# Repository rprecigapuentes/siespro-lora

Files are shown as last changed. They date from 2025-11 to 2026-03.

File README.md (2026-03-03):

# SIESPRO

<p align="center">
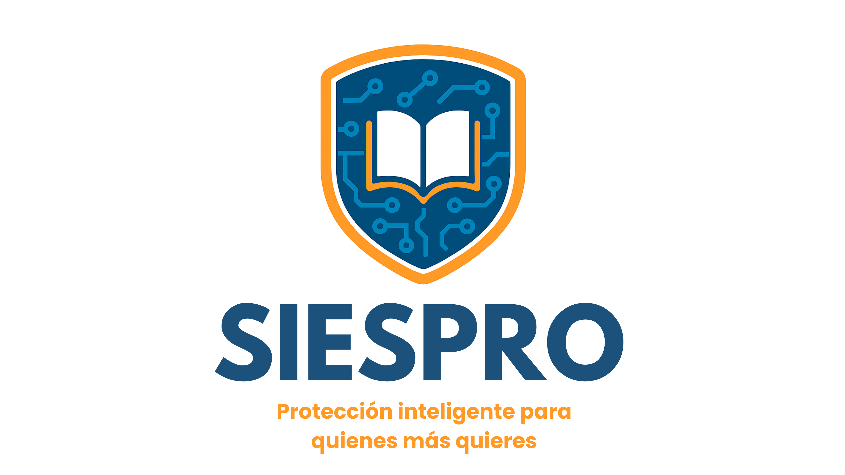
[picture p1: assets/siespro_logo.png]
SIESPRO Logo
  
</p>

<p align="center">
  <em>Sistema Estudiantil de Protección</em>
</p>

<p align="center">
  
  
  
  
  
  
  
  
</p>

---

SIESPRO is an interdisciplinary student project developed at the
[National University of Colombia — Bogotá campus](https://unal.edu.co/)
and presented at **TPI EXPOIDEAS 2025**, the university's annual innovation fair.
The project addresses a tangible problem in Colombian school environments:
**guaranteeing the physical safety of students without compromising their privacy.**

The solution combines IoT hardware, LoRa wireless communication, environmental
sensing, and a Machine Learning model trained from scratch — correlating
ambient variables (temperature, humidity, soil moisture) with RF link-quality
metrics (RSSI, SNR) to classify whether a student node is inside or outside
a defined perimeter. No GPS, no cameras, no biometric data.

Beyond the technical development, SIESPRO was structured as a **simulated
startup**, applying agile methodologies including **Design Thinking**,
**PESTEL analysis**, **Kanban**, **EDT**, **TRL**, and stakeholder-centered
divergence and convergence stages. A survey conducted with parents and school
administrators validated the problem and confirmed demand for a
privacy-preserving approach before any technical work began.

> Visit the project website: [ssiespro.wixsite.com/website-159](https://ssiespro.wixsite.com/website-159)

---

## System Architecture

<p align="center">
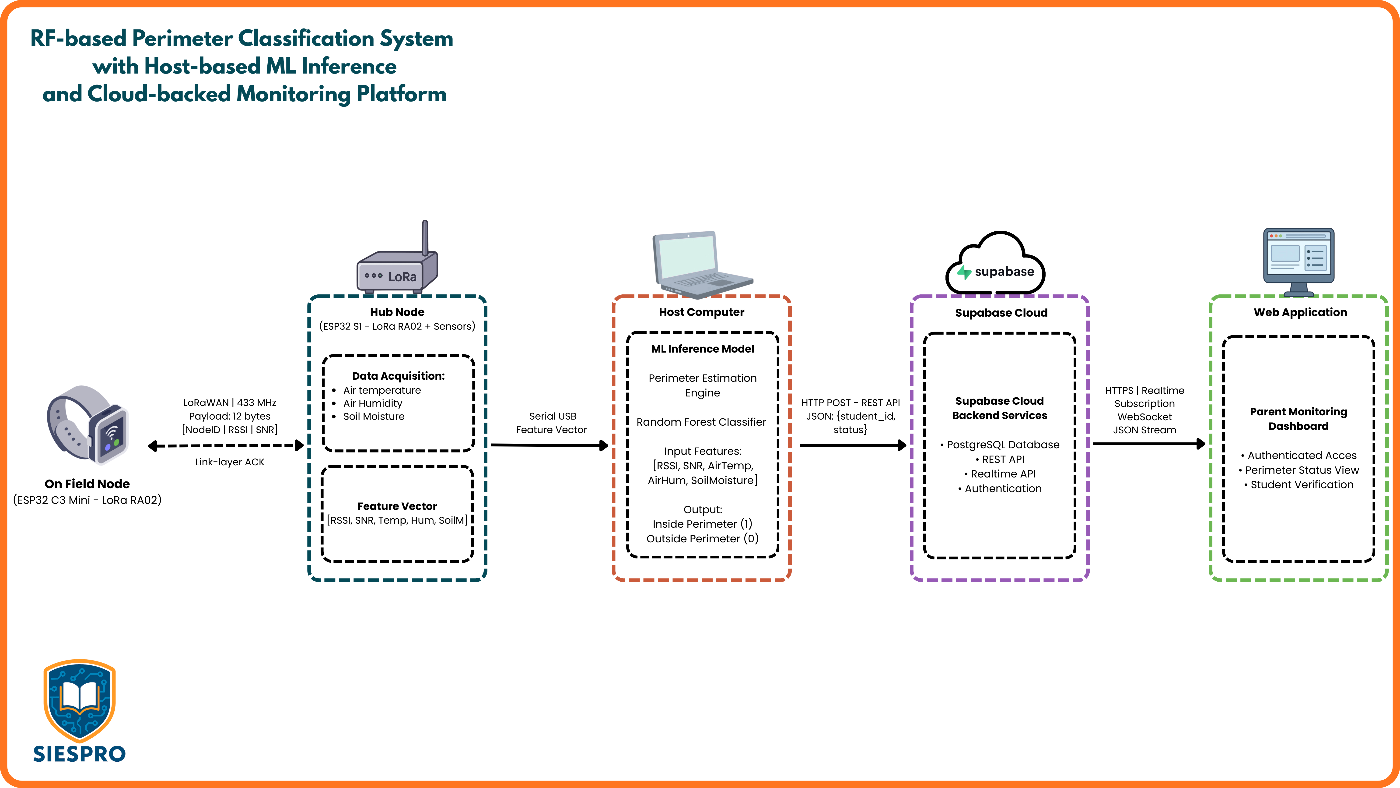
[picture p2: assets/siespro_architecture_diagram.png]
SIESPRO System Architecture
  
</p>

The On Field Node (ESP32-C3 Mini) exchanges LoRa packets with the Hub Node
(ESP32 + sensors). The Hub extracts RSSI and SNR from each ACK frame, bundles
them with local sensor readings, and sends the feature vector to a cloud-hosted
Random Forest classifier via HTTPS. The inference result feeds a real-time
parent-facing dashboard backed by Supabase.

---

## Hardware Prototype

<p align="center">
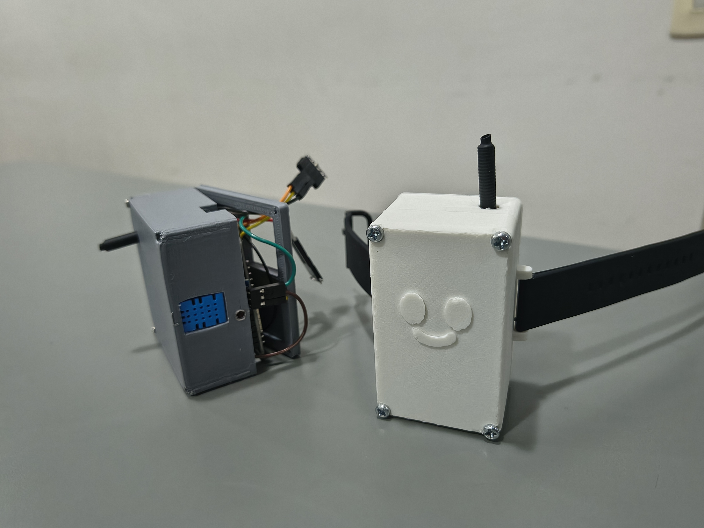
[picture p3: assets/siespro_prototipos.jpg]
SIESPRO Hardware Prototypes
  
</p>

Both nodes were fully assembled and tested on-site during the data collection
phase. Left: Hub Node (ESP32 + SX1278 + DHT11). Right: On Field Node
(ESP32-C3 Mini + SX1278).

---

## Team

SIESPRO was built by a genuinely interdisciplinary team, with each member
assigned a startup role matching their engineering background:

| Role | Name | Discipline |
|---|---|---|
| CEO | Luis Guillermo Vaca Rincón | Electronic Engineering |
| CTO | Rosemberth Steeven Preciga Puentes | Electronic Engineering |
| CFO | Andrés Felipe Castillo Caicedo | Mechanical Engineering |
| COO | Daniela Martínez Sierra | Civil Engineering |
| CCO | Miguel Alejandro Bermúdez Claros | Agricultural Engineering |
| CMO | Camila Stefany Garzón Parra | Anthropology |

---

## Repository Structure

| Folder | Contents |
|---|---|
| `hardware/` | All ESP32 firmware — master node, slave node, sensor tests and basic link tests. Each subfolder contains its own README with pin mappings, operating modes and flash instructions. |
| `frontend_backend/` | Web dashboard (parent monitoring UI) and Supabase backend — REST API, real-time subscriptions and PostgreSQL schema. |
| `3D_models/` | Enclosure and mounting models for the hardware nodes. |
| `assets/` | Project documentation — academic poster (TPI EXPOIDEAS 2025), business plan, PESTEL analysis, infographic, architecture diagram and hardware photographs. |

Each folder contains a dedicated `README.md`. Start with the folder most
relevant to your interest; the sections below suggest entry points by role.

---

## Entry Points by Role

**I want to understand the project**
→ Read [`assets/README.md`](assets/README.md) and review [`assets/siespro_poster.pdf`](assets/siespro_poster.pdf)

**I want to run the hardware**
→ Start at [`hardware/README.md`](hardware/README.md) → follow the recommended reading order inside

**I want to explore the ML model or backend**
→ Go to [`frontend_backend/README.md`](frontend_backend/README.md)

**I want to see the physical device**
→ See [`assets/siespro_prototipos.jpg`](assets/siespro_prototipos.jpg)

---

## Methodologies

| Methodology | Application in SIESPRO |
|---|---|
| Design Thinking | Divergence / convergence stages — problem framing and solution validation with stakeholders |
| PESTEL | Viability analysis across political, economic, social, technological, environmental and legal dimensions |
| Kanban | Sprint task management across the team |
| EDT (WBS) | Work breakdown structure for project planning |
| TRL | Technology readiness level tracking from concept to demo |
| Stakeholder mapping | Parents, school administrators and students as primary stakeholders |

---

## Disclaimer

SIESPRO is an academic research project developed for educational purposes.
System effectiveness depends on site-specific calibration and labeled data
collection. The system is designed to assist institutional safety efforts
and is **not intended for surveillance, behavioral tracking, or any use
outside a consensual, institutional safety context.**

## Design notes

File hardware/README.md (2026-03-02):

# SIESPRO — Hardware Subsystem









Embedded firmware for the SIESPRO perimeter monitoring system.
Implements a point-to-point LoRa network between a master node (ESP32) and a
slave node (ESP32-C3 Mini) using Reliable Transmission with AutoACK.
The link-quality metrics extracted from each ACK — RSSI and SNR — serve as
features for a Random Forest classifier that determines whether the transmitter
is inside or outside a defined perimeter.

> **Sensor data is never transmitted over LoRa.** The radio link is used solely
> as a measurement instrument to extract spatial RF features (RSSI, SNR).
> Environmental data (temperature, humidity, soil moisture) is read locally by
> the master node and sent directly to the backend API via HTTPS.

---

## System Architecture

```mermaid
flowchart LR
    subgraph Master ["Master Node (ESP32)"]
        DHT11["DHT11\ntemp / humidity"]
        HW080["HW-080\nsoil moisture"]
        MCU["ESP32"]
        SX_TX["SX1278\nLoRa TX"]

        DHT11 --> MCU
        HW080 --> MCU
        MCU --> SX_TX
    end

    subgraph Slave ["Slave Node (ESP32-C3 Mini)"]
        SX_RX["SX1278\nLoRa RX + AutoACK"]
    end

    subgraph Backend ["Backend"]
        API["REST API\nhttps://siespro.onrender.com"]
        RF["Random Forest\nclassifier"]
        API --> RF
    end

    SX_TX -->|"TX: SIESPRO\nNetworkID 0x3210\n434 MHz / SF7"| SX_RX
    SX_RX -->|"ACK: RSSI, SNR"| SX_TX
    MCU -->|"HTTPS POST\nJSON: temp, hum, rssi, snr"| API
```

---

## Repository Structure

| Folder | Target Hardware | Purpose |
|---|---|---|
| `basic_tests/` | ESP32 + ESP32-C3 Mini | Point-to-point link validation |
| `master_esp32/` | ESP32 | Main firmware — three operating modes |
| `slave_esp32_mini/` | ESP32-C3 Mini | AutoACK responder — passive |
| `sensors_esp32/` | ESP32 | Isolated sensor verification |
| `library/` | — | SX12XX-LoRa driver (Stuart Robinson) |

---

## Hardware Requirements

| Component | Model | Qty | Role |
|---|---|---|---|
| Microcontroller | ESP32 DevKit v1 | 1 | Master node |
| Microcontroller | ESP32-C3 Mini | 1 | Slave node |
| LoRa transceiver | SX1278 (433 MHz) | 2 | RF link |
| Air sensor | DHT11 | 1 | Temperature + humidity |
| Soil sensor | HW-080 | 1 | Soil moisture (optional) |

---

## Prerequisites

- [PlatformIO IDE](https://platformio.org/install/ide?install=vscode) (VSCode extension)
- Python 3.10+ — required only for `IA_config/dataset_tool/collect_dataset.py`
- `pyserial` — `pip install pyserial`

No additional library installation is needed. The SX12XX-LoRa driver is
vendored locally under `library/` and resolved automatically by PlatformIO
via `lib_extra_dirs` in each `platformio.ini`.

---

## Recommended Reading Order

Follow this order when setting up the system for the first time:

1. `library/` — understand the LoRa driver being used
2. `sensors_esp32/` — verify each sensor independently
3. `basic_tests/` — validate the LoRa link before adding logic
4. `slave_esp32_mini/` — flash the slave node (unchanged across modes)
5. `master_esp32/ACK_config/` — validate AutoACK end-to-end
6. `master_esp32/IA_config/` — collect the training dataset
7. `master_esp32/API_config/` — deploy online inference

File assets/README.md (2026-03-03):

# SIESPRO — Project Documentation



[]()
[]()

SIESPRO (*Sistema Estudiantil de Protección*) is a student
project from the **National University of Colombia — Bogotá campus** that goes
beyond a purely technical implementation. The project was structured around two
complementary axes: a **Design Thinking process** centered on the real needs of
stakeholders, and a **PESTEL analysis** to evaluate the viability and context of
the solution. The technical development (an RF-based perimeter classification
system using LoRa and Machine Learning) is the direct result of that process,
not the starting point.

The core problem addressed is **school child safety without compromising student
privacy**: a perimeter monitoring system that detects whether a student is inside
or outside a defined zone using RF signal features (RSSI, SNR), with no cameras
or biometric data involved.

---

## Project Phases

### Divergence — Problem Discovery

The divergence stage applied Design Thinking tools to identify and validate the
problem before committing to any technical solution. A survey was conducted with
the primary stakeholders — parents and school administrators — confirming both
the existence of the safety concern and the rejection of surveillance-based
approaches (cameras, GPS tracking). The outputs of this stage are:

- [**`siespro_infografia.pdf`**](siespro_infografia.pdf) — Visual summary of the problem space, the
  stakeholder map and the key insight that motivated the solution: families want
  safety guarantees without exposing children to invasive monitoring.

- [**`siespro_slides.pdf`**](siespro_slides.pdf) — Presentation used during the divergence review.
  Contains the PESTEL analysis across the six dimensions (Political, Economic,
  Social, Technological, Environmental, Legal), the survey methodology, results
  and the opportunity framing that bridged the problem into the solution space.

### Convergence — Solution & Validation

The convergence stage produced a defined, implementable solution and evaluated
its real-world viability as a product. The outputs of this stage are:

- [**`siespro_poster.pdf`**](siespro_poster.pdf) — Academic poster presented at **TPI EXPOIDEAS 2025**,
  the semiannual innovation fair of the National University of Colombia. Summarizes
  the full project — problem, methodology, technical architecture, results and
  conclusions — in a single-page format for a general audience.

- [**`siespro_plan_negocios.pdf`**](siespro_plan_negocios.pdf) — Business plan developed to assess the
  commercial and institutional viability of SIESPRO. Covers market analysis,
  value proposition, cost structure, revenue model and go-to-market strategy
  targeting Colombian educational institutions.

---

## Technical Reference

- [**`siespro_architecture_diagram.png`**](siespro_architecture_diagram.png) — System architecture diagram showing
  the data flow across all components: the On Field Node (ESP32-C3 Mini +
  SX1278), the Hub Node (ESP32 + sensors), the host-side ML inference engine
  (Random Forest classifier), the Supabase cloud backend and the parent-facing
  web dashboard. This diagram is the canonical reference for understanding how
  the hardware, firmware, ML model and backend interact
- [**`siespro_logo.png`**](siespro_logo.png) — Official SIESPRO logotype.
  Used as the project's visual identity across documentation, the web platform
  and the academic poster.

---

## Document Index

| File | Phase | Type |
|---|---|---|
| `siespro_infografia.pdf` | Divergence | Infographic |
| `siespro_slides.pdf` | Divergence | Presentation + PESTEL |
| `siespro_poster.pdf` | Convergence | Academic poster — TPI EXPOIDEAS 2025 |
| `siespro_plan_negocios.pdf` | Convergence | Business plan |
| `siespro_architecture_diagram.png` | Technical | System architecture diagram |
| `siespro_logo.png` | — | Brand asset |

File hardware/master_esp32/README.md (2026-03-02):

# Master Node — ESP32








Central node of the SIESPRO system. Reads environmental sensors, maintains a
LoRa link with the slave node to extract RF spatial features (RSSI, SNR from
each ACK), and operates in one of three selectable modes depending on the
project phase.

---

## Operating Modes

| Mode | Folder | Output | Purpose |
|---|---|---|---|
| **ACK** | `ACK_config/` | Serial debug | End-to-end AutoACK link validation |
| **IA** | `IA_config/` | CSV via Serial | Offline dataset acquisition for RF training |
| **API** | `API_config/` | HTTPS POST | Online inference — sends data to backend REST API |

Each mode is a standalone PlatformIO project. Flash only the mode needed for
the current project phase. The slave node firmware does not change across modes.

---

## Structure

```
master_esp32/
├── ACK_config/
│ ├── src/main.cpp
│ └── platformio.ini
├── IA_config/
│ ├── dataset_tool/
│ │ ├── collect_dataset.py
│ │ ├── mediciones_loRa_[2s].csv ← generated at runtime
│ │ └── mediciones_loRa_[3s].csv ← generated at runtime
│ ├── src/main.cpp
│ └── platformio.ini
└── API_config/
├── src/
│ ├── credentials.h ← not committed (see below)
│ └── main.cpp
└── platformio.ini
```

---

## Sensor Configuration

All modes support two sensor configurations selectable at compile time:

| Config | Sensors | CSV columns |
|---|---|---|
| **2S** (default, active) | DHT11 | `temp_C, hum_air_pct, rssi_dBm, snr_dB` |
| **3S** (commented `[3S]`) | DHT11 + HW-080 | `temp_C, hum_air_pct, soil_pct, rssi_dBm, snr_dB` |

To switch to 3S: uncomment all lines marked `[3S]` in both `src/main.cpp`
and (for IA_config) `dataset_tool/collect_dataset.py`. Both files must use
the same config simultaneously.

---

## Pin Mapping

| Signal | GPIO |
|---|---|
| LoRa SCK | 18 |
| LoRa MISO | 19 |
| LoRa MOSI | 23 |
| LoRa NSS | 5 |
| LoRa NRESET | 14 |
| LoRa DIO0 | 2 |
| DHT11 data | 17 |
| HW-080 analog | 33 |

---

## WiFi Credentials (API_config only)

Credentials are **not** stored in `main.cpp`. Create the following file
before building `API_config/`:

**`API_config/src/credentials.h`**
```cpp
#pragma once
#define WIFI_SSID     "your_ssid"
#define WIFI_PASSWORD "your_password"
```

Add it to .gitignore at the repo root:

```
hardware/master_esp32/API_config/src/credentials.h
```

## IA_config — Dataset Tool

IA_config/dataset_tool/collect_dataset.py reads CSV lines from the master
via Serial and writes labeled samples to disk for offline Random Forest training.

```
cd IA_config/dataset_tool
pip install pyserial
python collect_dataset.py
```

### Keyboard controls:

| Key | Action |
| ----- | --- |
| s | Start recording |
| p | Pause recording |
| Space | Toggle label 0 ↔ 1 |
| q | Quit |

Label semantics: 0 = outside perimeter, 1 = inside perimeter.

>The script filters out any Serial line that does not match the expected
>field count (4 for 2S, 5 for 3S). Debug prints in firmware are suppressed
>in IA_config intentionally to avoid parse errors.

## Recommended Phase Sequence

1. ACK_config   →  verify AutoACK link is stable
2. IA_config    →  collect labeled dataset (both classes, multiple positions)
3. API_config   →  deploy trained model to backend, begin online inference

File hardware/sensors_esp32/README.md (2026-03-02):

# Sensor Tests — ESP32






Isolated sensor verification firmware. Use these sketches to confirm correct
wiring and sensor response independently from the LoRa stack before integrating
sensors into the master node firmware.

---

## Structure

```
sensors_esp32/
├── dht11/
│ ├── src/main.cpp
│ └── platformio.ini
└── hw080/
├── src/main.cpp
└── platformio.ini
```

---

## DHT11 — Air Temperature & Humidity

**Pin:** GPIO 17

**Expected Serial output:**

```
Humidity: 54.00% Temp: 21.00 °C / 69.80 °F
```

**Common failure modes:**

| Output | Cause |
|---|---|
| `DHT11 read failed` repeatedly | Wrong GPIO, missing pull-up, or damaged sensor |
| Fixed value that never changes | Sensor not powered (3.3 V required) |
| Values update slower than 1 s | Normal — DHT11 maximum sampling rate is 1 Hz |

> A 10 kΩ pull-up resistor between the data line and VCC is required.
> Most breakout modules include it; bare sensors do not.

---

## HW-080 — Soil Moisture

**Pin:** GPIO 33 (ADC1 — required; ADC2 is unavailable when WiFi is active)

**Expected Serial output:**

```
Soil moisture: 42%
```

**Calibration:**

The `map()` function uses fixed ADC bounds:

```cpp
map(analogRead(SOIL_PIN), 4092, 0, 0, 100)
//                         ^^^^  ^
//                         dry   saturated
```

These values are empirical for a 12-bit ESP32 ADC. If readings at known
dry/wet states do not reach 0% or 100%, adjust the bounds:

1. Read raw ADC with sensor fully dry in air → use that value as the 4092 bound
2. Read raw ADC with sensor fully submerged → use that value as the 0 bound
3. Update both arguments in map() accordingly

>GPIO 33 is input-only on the ESP32 — do not use it for output.
>ADC readings are nonlinear near the rails; values below ~5% and above ~95%
>may be unreliable without additional calibration.

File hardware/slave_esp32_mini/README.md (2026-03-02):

# Slave Node — ESP32-C3 Mini






Passive AutoACK responder for the SIESPRO LoRa network.
The slave node listens for packets matching the project `NetworkID (0x3210)`,
and automatically sends an ACK containing its own RSSI and SNR measurements
back to the master. It carries no sensors and requires no configuration
changes across operating modes.

---

## Role in the System

```
Master (ESP32) ──[TX: "SIESPRO", NetworkID=0x3210]──► Slave (ESP32-C3 Mini)
Master (ESP32) ◄──[ACK: RSSI, SNR]──────────────────── Slave (ESP32-C3 Mini)
```

The RSSI and SNR values embedded in the ACK are the spatial RF features
extracted by the master to feed the Random Forest classifier.

---

## Structure

```
slave_esp32_mini/
├── src/
│ └── main.cpp
└── platformio.ini
```

This firmware is **single and shared** across all master operating modes
(ACK_config, IA_config, API_config). Flash once; no changes needed.

---

## Pin Mapping (ESP32-C3 Mini)

| Signal | GPIO | Note |
|---|---|---|
| SCK | 10 | |
| MISO | 5 | |
| MOSI | 6 | |
| NSS | 7 | |
| NRESET | 3 | |
| DIO0 | 2 | Interrupt input — driven by SX1278, not MCU |

> GPIO2, GPIO8 and GPIO9 are hardware strapping pins on the ESP32-C3.
> The SX1278 drives DIO0 only after boot is complete, so GPIO2 is safe
> as an interrupt input but must not be pulled externally at startup.

---

## LoRa Parameters

Must match the master node exactly:

| Parameter | Value |
|---|---|
| NetworkID | `0x3210` |
| Frequency | 434 MHz |
| Spreading Factor | SF7 |
| Bandwidth | 125 kHz |
| Coding Rate | 4/5 |
| ACK Timeout | 1000 ms |

---

## Flash Instructions

```console
# From slave_esp32_mini/ directory
pio run --target upload
pio device monitor --baud 115200
```

Expected Serial output on each received packet:

```
LocalNetworkID,0x3210,ReceivedPayloadCRC,0x<CRC>,RSSI,-<n>dBm,SNR,<n>dB
```

Packets with a non-matching NetworkID are silently discarded by the library.

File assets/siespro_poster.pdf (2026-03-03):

Rosemberth Preciga
rpreciga@unal.edu.co

Diseñar el dispositivo portátil (manilla) con las especificaciones técnicas requeridas para la comunicación LoRa, garantizando un uso cómodo y adaptable.

Estructurar el protocolo de comunicación LoRa para la conexión fiable entre dispositivos, receptores y la plataforma de alertas.

Construir el prototipo funcional, integrando los componentes de hardware (dispositivos y receptores) y software (plataforma de alertas).

Evaluar el desempeño técnico del prototipo en un entorno de baja conectividad para validar su alcance, precisión y escalabilidad

Costos unitarios estimados: Manilla ≈ $114.210 COP
Host ≈ $141.800 COP.

En Colombia, el mercado proyecta 53.000 instituciones educativas

Modelo Random Forest que determina condición dentro/fuera del perímetro.

# Modelo económico

# Introducción

# Objetivos

# Partes interesadas

# Solución

# Limitaciones y Requerimientos

Grupo 22

Luis Vaca
lvacar@unal.edu,co

Miguel Bermudez
mibermudez@unal.edu.co

Andres Castillo
ancastilloc@unal.edu.co

Camila Garzón
cgarzonpa@unal.edu.co

Daniela Martínez
dmartinezsi@unal.edu.co

PSrotec

I

cióEn inteSligentPe paraRquienOes más quieres

### Prototipo funcional completo con flujo IoT:

hardware, LoRa, backend y visualización web.

Limitaciones:

Entrenamiento propio del
modelo IA.
Tamaño actual del hardware. Robustez de la carcasa.
Detección limitada a
“dentro/fuera” del perímetro.

¿Sabías que, en Colombia, a enero de
2025, se registraron 3.201 solicitudes de
búsqueda de menores?

Aunque existe normativa sobre el cuidado escolar, no hay un protocolo unificado ni herramientas tecnológicas que permitan reaccionar de inmediato ante una salida no autorizada.

La mayoría de los colegios aún dependen de torniquetes, códigos QR o registros manuales, sistemas limitados a los puntos de acceso y que no cubren el perímetro real.

SIESPRO propone una alternativa no invasiva basada en comunicación inalámbrica, capaz de identificar si un estudiante está dentro o fuera del colegio sin rastreo continuo ni infraestructura compleja.

Acudientes: Necesitan información rápida y confiable para garantizar la seguridad de sus hijos y reducir la incertidumbre ante posibles riesgos.

Docentes: Manejan sobrecarga operativa y necesitan apoyo tecnológico que facilite la supervisión y reduzca fallas humanas.

Directivos: Requieren protocolos claros, trazabilidad y herramientas que fortalezcan la gestión institucional y la respuesta ante emergencias.

Estudiantes: Especialmente menores de edad, necesitan un entorno seguro y un sistema no invasivo que permita monitoreo sin afectar su autonomía.

Desarrollar una solución tecnológica accesible que permita detectar salidas no autorizadas mediante comunicación inalámbrica de largo alcance (LoRa), sin rastreo invasivo y adaptable a instituciones con baja conectividad.

Objetivo General:

Determinar la viabilidad económica del sistema mediante el análisis de costos de producción, el modelo de negocio (TAM-SAM-SOM) y la proyección financiera.

Objetivos específicos:

Requerimientos:

Integración HW–FW–LoRa–API. Pruebas de campo para
calibración.
Nodo maestro con energía e internet mínimo.
Cumplimiento de Ley 1581 y consentimiento informado.

SOM

SAM

TAM

Manilla LoRa impresa en 3D, capaz de responder al polling del nodo maestro.

Este representa un 20% del mercado total, es decir 10.600
A co | instituciones.

rto/mediano plazo se aspira que
este represente el 10% del SAM, es
decir 1.060 instituciones educativas

TIR: 73.9% y VPN positivo: $1.374 millones COP a 5 años, indicando alta rentabilidad y recuperación en menos de 1.88 años.

Modelo híbrido HaaS + SaaS: Pago por instalación inicial + suscripción anual por estudiante, lo que facilita adopción y reduce barreras de inversión.

Ventaja competitiva: arquitectura LoRa/LoRaWAN reduce CAPEX, permite operar sin internet y abre acceso al 90% de instituciones con infraestructura limitada.

Nodo maestro obtiene RSSI, SNR y variables ambientales para clasificación.

Dashboard web que muestra estado del estudiante y genera alertas en tiempo real.

API desplegada y conexión con base de datos en la nube para almacenamiento y procesamiento.

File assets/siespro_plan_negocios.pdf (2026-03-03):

## Plan de Negocios: SIESPRO (Sistema Inteligente de Seguridad y Permanencia Escolar)

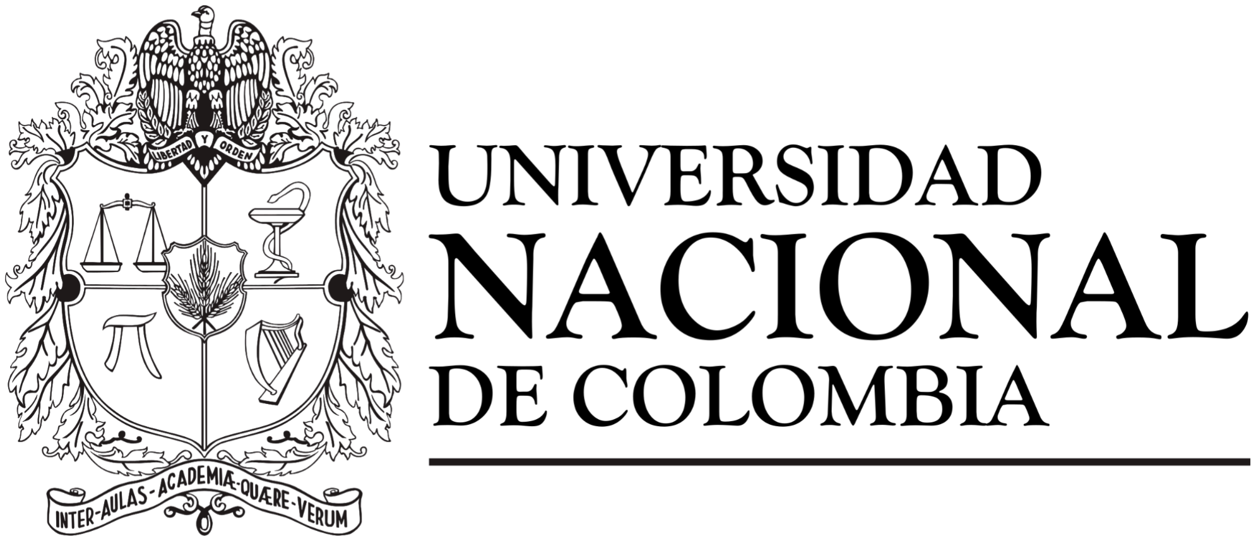
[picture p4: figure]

Autores:
Andrés Felipe Castillo Caicedo Daniela Martínez Sierra
Luis Guillermo Vaca Rincón Miguel Alejandro Bermúdez Claros Rosemberth Steeven Preciga Puentes Camila Stefany Garzón Parra

Taller de Proyecto interdisciplinario Universidad Nacional de Colombia

Fecha: Noviembre 30 2025

Resumen
SIESPRO es un sistema de control de asistencia escolar diseñado y adaptada para la realidad de Latinoamérica y en especial de Colombia. Permite el uso de una solución no invasiva sustentada en la tecnología LoRa y dispositivos wearables y que asegura el control de la salida no autorizada de estudiantes (de 3 a 12 años) en instituciones educativas que tienen una alta probabilidad de baja conectividad.
El modelo de negocio está enfocado hacia una suscripción B2B (Business-to-Business) con las instituciones educativas y posee un alto valor social, ético y operativo: reduce el riesgo de las salidas no autorizadas, disminuye la sobrecarga laboral del docente y proporciona tranquilidad a los padres. El análisis financiero muestra que la viabilidad económica tiene una Tasa Interna de Retorno (TIR) del 73.9% y el Valor Presente Neto (VPN) es de $1.374 millones COP a 5 años, mostrando una fuerte rentabilidad y un tiempo de recuperación de la inversión inferior a los 2 años. SIESPRO se establece en un nuevo nicho de mercado (Océano Morado), una combinación de la innovación tecnológica y el impacto social en la seguridad infantil.

### 1. Fundamentación y origen de la idea de negocio

Para comenzar, es fundamental tener en cuenta los riesgos externos y contextuales que atraviesan la seguridad escolar. Datos proporcionados por la UBPD (Unidad de Búsqueda de Personas Dadas por Desaparecidas), con corte a enero de 2025, registran 3.201 solicitudes de búsqueda de niños, niñas y adolescentes. De estas personas, 88 son niñas, 182 son niños y 2.914 son adolescentes. Esta situación agrava las preocupaciones de los padres y acudientes, caracterizando las salidas no autorizadas como un riesgo real y latente, que va más allá de un simple problema disciplinario, constituyéndose en un riesgo de seguridad.

Aunque la normatividad colombiana establece responsabilidades claras frente al cuidado de menores en jornada escolar (Función Pública, Norma 6405), en la práctica no existe un protocolo específico; por este motivo, el protocolo no está unificado, ni tecnológicamente soportado para atender eventos en los que un niño se aleja del aula, sale del plantel o se pierde dentro de la institución.

Este vacío es más preocupante si se contrasta con datos que dan cuenta de la desigualdad en la infraestructura escolar en Colombia. Esto se ve reflejado en situaciones en las cuales no se cuenta ni siquiera con las barreras físicas nombradas anteriormente, delegando toda la responsabilidad en los docentes encargados de los niños. Por otro lado, Mazo (2025) habla de cómo más de 21.000 sedes educativas carecen de acceso a internet, y un aproximado de 5.000 carecen de electricidad, imposibilitando el uso de soluciones tecnológicas basadas en conectividad Wi-Fi o plataformas digitales. En otras palabras, los colegios no solo carecen de protocolos, sino que tampoco poseen condiciones técnicas que permitan implementar tecnologías convencionales de monitoreo estudiantil.

2. Propuesta de valor y componente de innovación

La propuesta de SIESPRO no es solo tecnológica, sino principalmente ética y contextual. Su valor se centra en transformar la gestión de la seguridad escolar, pasando de un modelo reactivo, basado en barreras físicas y vigilancia humana sobrecargada, a un sistema proactivo, de bajo requerimiento técnico y diseñado para adaptarse a las profundas inequidades infraestructurales del sistema educativo colombiano.

SIESPRO se posiciona como la herramienta esencial para que las instituciones educativas garanticen la permanencia de estudiantes entre 3 y 12 años sin sacrificar su autonomía o privacidad. El equipo SIESPRO ofrece a la comunidad educativa tranquilidad y prevención mediante la detección inmediata de eventos de salida no autorizada del perímetro seguro. Adicionalmente, el sistema actúa como un apoyo continuo, aliviando la carga docente y reduciendo la vulnerabilidad de la vigilancia generada por la sobrecarga de tareas que cumple el personal escolar.

Frente a esta situación, es necesario tener presente que actualmente el mercado de seguridad escolar ofrece principalmente tres tipos de soluciones: sistemas de cámaras de vigilancia, aplicaciones de control de asistencia y tecnologías de rastreo de ubicación precisa como GPS o soluciones RFID. Es en este panorama en el que SIESPRO se impone como una alternativa respetuosa y efectiva frente a las dificultades de las principales competencias. Al no rastrear la ubicación específica del estudiante dentro de la institución, se asegura el cumplimiento de la ley y se promueve la confianza necesaria en acudientes y docentes, lo que constituye una ventaja decisiva.

De esta forma, la innovación de SIESPRO se expresa en su capacidad para ofrecer una solución tecnológica, pero contextualizada para superar las barreras del entorno educativo. El proyecto está diseñado con el propósito de ser escalable y adaptable: mientras que la fase inicial de exploración utiliza conectividad Wi-Fi para facilitar las pruebas piloto, la base tecnológica se encuentra orientada a evolucionar hacia LoRaWAN (una red de largo alcance y bajo consumo). Este diseño permite que el sistema pueda ser operable en entornos rurales o con infraestructura precaria.

3. Modelo y estrategia de negocio
3.1. Modelo Canvas

El modelo de negocio de SIESPRO ha sido estructurado con el método del Business Model

Canvas (BMC) creando un modelo mixto de Hardware as a Service (HaaS) y Software as a Service (SaaS) centrado en el espacio de mercado que ha sido denominado Océano Morado a partir de su base ética, de privacidad y tecnología accesible.

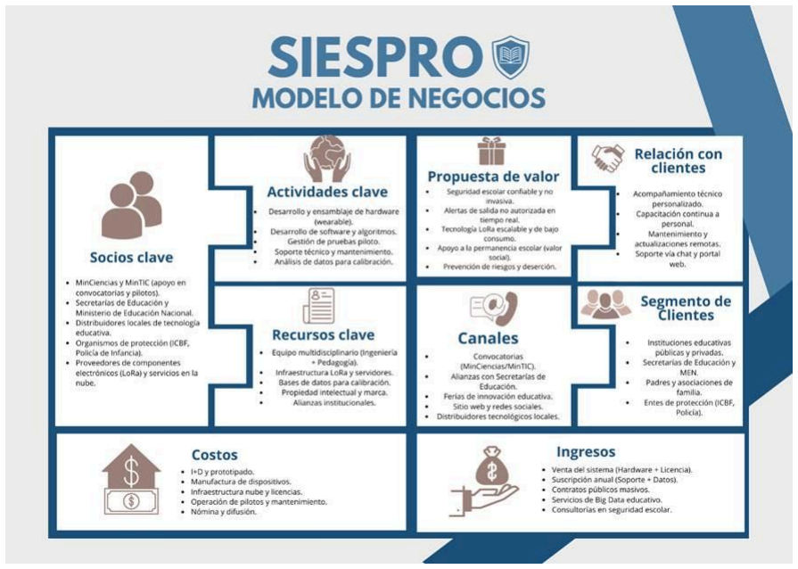
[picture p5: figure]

Figura 1.Business Model Canvas (BMC) de SIESPRO Fuente: Elaboración propia basada en Osterwalder y Pigneur (2010).

3.1.1. Segmentos de clientes (CS)

Este modelo contempla cuatro partes interesadas relevantes a las que se interpela de manera diferente para garantizar la compra del producto: 1) Directivo/Administrativo: quien toma la decisión de aprovisionamiento motivado por la reducción del riesgo legal e incurrido en reputación; 2) Docente/Personal: quien es el usuario directo del sistema y quiere la seguridad de los estudiantes, pero igualmente quiere aliviarse con el desgaste de la sobrecarga de ejecución; 3) Acudiente/Padre de Familia: motivado por la tranquilidad y la notificación rápida; y 4) Niño/Estudiante: quien es el sujeto central del servicio y la seguridad y protección es el objetivo final.

3.1.2. Propuesta de valor (VP)

La propuesta se orienta a la Seguridad Escolar No Invasiva, que pretende advertir las salidas no permitidas y los extravíos en el tiempo real mediante detecciones perimetrales, distinguiéndose por su ética, así como por su alineamiento con la Ley 1581 (Protección de Datos), pues no se intenta rastrear la ubicación del menor, sino que mediante un acuso de respuesta intenta detectar la presencia/ausencia en un perímetros definido, reduciendo así la invasión de la privacidad, además de que el sistema promueve la adaptabilidad en la baja conectividad y grandes distancias dentro del campus gracias a la buena utilización de la tecnología LoRa.

3.1.3. Canales (CH)

La comercialización de SIESPRO se apoya en una estrategia de Venta Directa Institucional (B2B), fortaleciendo la confianza y el acompañamiento técnico a las instituciones. Los canales de penetración incluyen la venta directa a colegios privados y las alianzas estratégicas con el Ministerio de Educación Nacional (MEN) para instituciones públicas. El soporte se gestiona mediante una plataforma web y una aplicación móvil para la administración de alertas y la comunicación con acudientes.

3.1.4. Relación con clientes (CR)

La relación con clientes es cimentada por medio de la confianza, la transparencia y el soporte técnico continuo. Para cumplir con esto se requiere capacitación al personal y el uso protocolo claro frente al consentimiento informado. Este protocolo no es solo una herramienta de gestión, sino un requisito legal crítico que habilita la operación, ya que el proyecto se encuentra sujeto al cumplimiento de la Ley 1581 de 2012 (Protección de Datos Personales). Dicha normativa exige el consentimiento previo, expreso e informado del acudiente, asegurando su derecho a conocer, actualizar, rectificar y suprimir los datos del menor (Ley 1581 de 2012, artículo 7°). La implementación de este protocolo es esencial para abordar la posible resistencia al cambio, garantizando a la comunidad educativa que dicha tecnología se utiliza únicamente con el fin de brindar seguridad y prevención.

3.1.5. Fuentes de ingreso (R$)

Los ingresos se basan en un modelo híbrido recurrente (HaaS + SaaS). Este se compone de dos cobros: 1) un Fee de Instalación Inicial único por el despliegue de la red LoRa (dispositivos Host/Gateways) y la configuración de la plataforma, y 2) una Suscripción Anual/Mensual (Recurrente), que constituye el ingreso principal. Esta suscripción se cobra por estudiante/manilla e incluye el acceso a la plataforma, el mantenimiento continuo del dispositivo wearable y el soporte técnico, amortizando en el tiempo el costo unitario del dispositivo.

3.1.6. Recursos clave (KR)

IA:

Plataforma de IA de Localización: Algoritmos patentados para estimar la posición por

RSSI/SNR.

Patentes de diseño/software.

Red de gateways LoRa.

Hardware:

Módulos LoRa: Componentes electrónicos clave que permiten la comunicación de largo alcance y bajo consumo energético.

Microcontroladores: Uso de ESP32 en nodos esclavos y Arduino en nodos maestros, garantizando un prototipo funcional (TRL 4, 5 y 6).

Diseño de PCB y carcasa: El diseño adaptado de la placa de circuito impreso (PCB) y la carcasa (case) ergonómica del dispositivo wearable (manilla) son recursos físicos de diseño esenciales para la usabilidad y durabilidad.

Plataforma de software y conectividad:

Base de datos en la nube: Donde se almacena la información de asistencia y alertas.

API y Dashboard: Interfaz donde los docentes, directivos y acudientes recibiranr las alertas en tiempo real y gestionaran la información.

Recursos legales

Protocolo de Consentimiento Informado: Asegura el cumplimiento de la Ley 1581 de 2012 (Protección de Datos Personales), exigiendo la autorización previa, expresa e informada del acudiente para el tratamiento de los datos del menor.

Política de tratamiento de datos: Aquí es donde se define el flujo de información; este recurso es indispensable para demostrar la debida diligencia ante la Superintendencia de Industria y Comercio (SIC).

3.1.7. Actividades clave (KA)

Las actividades fundamentales para la realización del proyecto son la innovación tecnológica y la gestión estratégica de la confianza. Con respecto a la innovación, es muy importante el I+D+i porque es el motor de la mejora del algoritmo de detección de distancia basado en RSSI/SNR y su futura evolución a LoRaWAN, asegurando la escalabilidad y la fiabilidad del sistema no invasivo. A su vez, esta actividad intelectual culmina con la actividad operacional por la cual se producen, ensamblan y logísticas de los dispositivos wearables (manillas) y los gateways, asegurando la entrega de hardware diferenciado a través de un procedimiento eficaz económicamente.

El segundo pilar del modelo de negocio es la Gestión de la Confianza, actividad clave para la viabilidad social y legal del proyecto. Esta actividad implica la gestión práctica y estricta de la ética de los datos y la privacidad del menor en cuyo impacto y control se encuentra garantizada la entrega de las pruebas del cumplimiento de la Ley 1581 de 2012 e implementación del Protocolo de Consentimiento Informado.

3.1.8. Estructura de costos (C$)

La estructura de costos presenta una alta proporción de costos variables derivados de la producción de hardware, compensada por una rentabilidad proyectada elevada gracias al modelo de suscripción. La inversión inicial en activos fijos es de $35.000.000 COP, mientras que la necesidad de financiación para cubrir el capital de trabajo asciende a $827.706.313 COP. Los costos unitarios del hardware se estiman en $114.210 COP para la manilla (dispositivo esclavo) y $141.800 COP para el host (dispositivo maestro). Los costos fijos se concentran principalmente en nómina, I+D y gastos administrativos y operativos.

3. 2. Estrategia y Metas de Crecimiento

La estrategia se centra en la adopción temprana en el mercado urbano-conectado, seguida por la migración a tecnología LoRaWAN para penetrar el mercado rural y de baja conectividad, según la matriz ERAC (Estudio de Mercado, 14.3): Crear un nuevo mercado de seguridad escolar no invasiva.

Plazo | Metas Estructuradas y Medibles | Indicadores (KPI)
Corto Plazo (Año 1-2) | Validación y Consolidación: Implementar el piloto en 5 instituciones. Asegurar la certificación TRL 7 (Prototipo demostrado en entorno real) y TRL 8 . Alcanzar el Punto de Equilibrio (Punto de Equilibrio: 1,88 años). | TRL, N.º de colegios implementados, Punto de Equilibrio, Tasa de Churn.
Mediano Plazo (Año 3-4) | Escalabilidad y Expansión: Implementar la migración tecnológica a LoRaWAN. Duplicar la base de clientes. Explorar alianzas público-privadas para subsidios o pilotos en zonas rurales | Retorno sobre la Inversión (ROI), N.º de estudiantes cubiertos, Penetración en mercado rural.

Largo Plazo
(Año 5+)

Liderazgo y Diversificación: Liderar el segmento EdTech de seguridad escolar en Colombia. Exportar el modelo de solución a otros países de LATAM con infraestructuras similares. Diversificar la oferta con trazabilidad de bienestar estudiantil.

TIR, Expansión geográfica, Market Share, LTV
(Lifetime Value).

Tabla 1. SIESPRO. (2025). Metas estructuradas, indicadores y plazos del proyecto [Tabla no publicada].

4. Análisis del Mercado y Ventajas Competitivas
4.1. Análisis del Mercado Objetivo (TAM, SAM, SOM)

El TAM incluye todas las instituciones educativas de preescolar y primaria —nuestra población considerada la de los niños entre 3 y 12 años— dentro del contexto colombiano y de potenciales mercados latinoamericanos. Este universo responde a dos presiones estructurales: la necesidad de mejorar la seguridad infantil y la necesidad de reducir la carga de la supervisión por parte de los docentes y los directivos. En Colombia se registraron más de 53.400 sedes educativas (DANE, 2017), siendo alrededor de 19.600 de educativas oficiales y no oficiales. Esto representa un mercado potencial muy grande de estudiantes susceptibles a obtener mecanismos de control de permanencia seguros y respetuosos con la privacidad de estos. La oportunidad estratégica se puede ampliar aún más a partir de las limitaciones en la infraestructura del país a nivel de conectividad evidenciando un rezago estructural. Ante ello, la arquitectura tecnológica LoRaWAN de SIESPRO —la cual permite no tener dependencia de internet y operar con mínima infraestructura— genera un habilitador clave que busca maximizar el TAM a largo plazo y eliminar gradualmente la brecha digital.

El SAM ( Serviceable Availble Market) se ve definido por la capacidad tecnológica y operativa actual de SIESPRO y su nicho dentro del Océano Morado. En este punto la empresa incluye escuelas que ya tienen capacidad económica o presupuestaria para invertir en seguridad y que buscan activamente alternativas no invasivas. En una segmentación inicial, se proyecta un SAM de 2,160 (Secretaría de Educación del Distrito, 2025) instituciones de la ciudad de Bogotá y sus alrededores en la primera fase (5 años). componiendose de:

- IE Privadas Urbanas: Con alta preocupación por la reputación y la demanda de seguridad por parte de los padres (Buyer Persona Acudiente/Directivo).

- IE Públicas/Semi-urbanas: Con acceso a programas de digitalización (MinCiencias, iNNpulsa) que subsidian la inversión en seguridad preventiva, que se verían beneficiadas por el bajo requerimiento de infraestructura de LoRa.

El SOM (Serviceable Obtainable Market) propone una meta realista de penetración basada en la capacidad de ventas y recursos humanos proyectados para el corto y mediano plazo (1-5 años).

- Año 1: Consolidación del piloto en 5 instituciones, enfocándose en la obtención de la certificación TRL 7 (prototipo demostrado en entorno real) y la validación ética.
- Año 3: Crecimiento acelerado a 25-30 instituciones tras la recuperación de la inversión (Punto de Equilibrio: 1.88 años) y el uso del VPN ($1.374B COP) y la TIR (73.9%) para apalancar la expansión.
- Año 5: Penetración de más de 100 colegios con la consolidación de la migración a la tecnología LoRaWAN, lo que permitirá a SIESPRO atacar segmentos del SAM en áreas de menor conectividad, maximizando su alcance.
4.2. Análisis Competitivo y Ventajas Sostenibles

Tecnología Anti-Brecha Digital: A partir del paso hacia LoRaWAN ya no es necesario realizar inversiones en las infraestructuras que están basadas en redes Wi-Fi para realizar el seguimiento de las personas, por lo que se hace probablemente accesible al 90% de las instituciones de Colombia, basándose en presupuestos que tengan una infraestructura de internet, energía eléctrica u otro tipo de conexión.

Liderazgo Ético y de Privacidad: Al solo llevar el registro de las salidas perimetrales y no de los movimientos dentro del plantel, SIESPRO disminuye el riesgo social de ser percibido como una 'herramienta de sanción' y cumple con la Ley 1581 de 2012 (protección de datos personales).

Modelo de Costo (OPEX): El modelo de suscripción facilita la adopción institucional en el sentido en que la inversión se convierte en gasto operativo predecible y fácil, no existiendo la barrera que suponen los costes del CAPEX de las soluciones basadas en hardware típico.

5. Proyección y Viabilidad Financiera (2025-2029)

El análisis se basa en una proyección a cinco años (2025-2029), utilizando los datos del Simulador Financiero 2025. equipo 22 - 5 colegios, el cual fue anexo a los documentos de respaldo.

5.1. Proyección de Ventas

La proyección se basa en la venta de dos productos clave: la Manilla (Dispositivo Esclavo) y el Host (Dispositivo Maestro). Se proyecta un crecimiento anual constante del 5% en cantidades vendidas, con un incremento de precio que asegura la rentabilidad.

Indicador (COP) | 2025 (Año 1) | 2026 (Año 2) | 2027 (Año 3) | 2028 (Año 4) | 2029 (Año 5)
Ingresos Totales | $2.194.000.000 | $2.390.410.200 | $2.622.009.824 | $2.840.314.309 | $3.094.728.998
Costo de Ventas (CV) | $386.217.000 | $417.213.499 | $450.721.808 | $486.946.206 | $526.107.609
Utilidad Bruta | $1.807.783.000 | $1.973.196.701 | $2.171.288.016 | $2.353.368.102 | $2.568.621.388

Tabla 2. SIESPRO. (2025). Proyección de ventas [Tabla en anexos].

5.2. Inversión Inicial y Estructura de Costos (CAPEX y OPEX)
5.2.1. Inversión de Capital (CAPEX)

La inversión inicial total (CAPEX) para la puesta en marcha del negocio se establece en $35.000.000 COP, enfocada en activos a largo plazo y la fase de desarrollo tecnológico.

Rubro CAPEX | Valor (COP) | Concepto
Propiedad, Planta y Equipo | $12.000.000 | Equipos de fabricación y laboratorio.
Muebles y Enseres | $6.000.000 | Mobiliario de oficina.
Equipo de Oficina | $2.000.000 | Computadoras y periféricos.
Patentes / Inv. Intangibles | $5.000.000 | Propiedad intelectual (Modelo IA de RSSI).
Gastos de Puesta en Marcha | $10.000.000 | Registro legal, licencias operativas iniciales.

Inversión total Inicial | **$35.000.000**

Tabla 3. SIESPRO. (2025). Inversión de capital [Tabla en anexos, hoja 2].

5.2.2. Costos Operacionales (OPEX)

Los costos operativos (OPEX) del primer año ascienden a $1.326.861.370 COP, siendo la nómina administrativa y de ventas el componente más significativo, seguido de los costos de producción (CV) y gastos fijos.

Rubro OPEX (Año 1) | Valor (COP)
Nóminas (Admin. y Ventas) | $700.000.000
Costos Operativos/Producción (CV) | $386.217.000
Gastos Fijos (Arriendo, Servicios, etc.) | $55.842.469
Marketing Mix / Otros | $184.801.901
Total OPEX Proyectado | **$1.326.861.370**

Tabla 4. SIESPRO. (2025). Costos operacionales [Tabla en anexos, hojas 2 y 4].

6.3. Viabilidad y Rentabilidad Proyectada

La evaluación de la viabilidad se realiza utilizando los indicadores clave TIR, VPN, ROI y el Punto de Equilibrio, asumiendo una Tasa de Evaluación del Proyecto (WACC) del 21%.

6.3.1. Indicadores de Rentabilidad

Los indicadores demuestran que SIESPRO es un proyecto de alta rentabilidad y bajo riesgo de recuperación, superando ampliamente la Tasa de Evaluación del 21%.

- Tasa Interna de Retorno (TIR): 73.9%
- Análisis: Al ser la TIR ($73.9\%$) significativamente mayor que la Tasa de Evaluación del Proyecto ($21\%$), el proyecto es altamente rentable y atractivo para los inversionistas.

- Valor Presente Neto (VPN): $1.374.494.987 COP
- Análisis: Un VPN positivo y elevado indica que el valor presente de los flujos de caja futuros es superior a la inversión inicial, generando riqueza neta.
- Período de Recuperación de la Inversión: 1.88 años
- Análisis: La inversión inicial se recupera en menos de dos años, lo que se considera un período corto para un proyecto de desarrollo tecnológico (Hardware/Software), mitigando el riesgo de liquidez.
6.3.2. Flujo de Caja del Proyecto
Indicador (COP) | Inversión (Año 0) | 2025 (Año 1) | 2026 (Año 2) | 2027 (Año 3) | 2028 (Año 4) | 2029 (Año 5)
Flujo de Caja del Proyecto | -$827.706.313 | $328.536.385 | $895.732.860 | $1.028.001.030 | $804.318.933 | $942.528.479

Tabla 5. SIESPRO. (2025). Flujo de caja del proyecto [Tabla en anexos, hoja 5].

6.3.3. Punto de Equilibrio y Cobertura

El análisis del Punto de Equilibrio (PE) valida la solidez operativa del negocio, determinando el volumen de ventas necesario para cubrir todos los costos fijos y variables.

- Punto de Equilibrio Total (Unidades): 2.932 Manillas y 7.4 Hosts
- Para alcanzar el punto de equilibrio, SIESPRO debe vender el equivalente a 2.932 Manillas y 7.4 Hosts.
- Margen de Contribución Ponderado: $543.393 COP

Este margen indica que, después de cubrir los costos variables, cada unidad ponderada contribuye positivamente a cubrir los costos fijos y generar ganancias.

6.3.4. Evaluación de Riesgos y Mitigación

El proyecto enfrenta riesgos gestionables, siendo la resistencia al cambio y la ausencia de normativa clara los de mayor impacto.

Categoría de
Riesgo

Riesgo de Mayor Impacto Mitigación y Control

Tecnológico | Falla en la comunicación LoRa (Media-Alta) | Foco en la certificación TRL 7 (Piloto en entorno real). Diseño de gateways energéticamente eficientes para entornos rurales.
Económico | Falta de recursos para implementación (Alta-Alta) | Búsqueda activa de alianzas con entidades gubernamentales (MinCiencias, iNNpulsa) y uso de modelo OPEX (suscripción).
Social | Resistencia al cambio de la comunidad educativa (Alta-Alta) | Campañas de sensibilización y capacitación. Énfasis en el enfoque no invasivo y ético de la solución.
Legal | Ausencia de normativa clara sobre tecnologías de rastreo (Alta-Alta) | Protocolo de consentimiento informado y cumplimiento estricto de la Ley 1581 (Protección de Datos) y Ley 1098 (Protección Integral de la Infancia).

Tabla 6. SIESPRO. (2025). Matriz de riesgos e incertidumbres [Tabla en anexos].

Referencias

Carranza, L. (2017). Infancias, cuerpos y subjetividades en la escuela. Revista Infancias Imágenes, 16(2). Universidad Distrital Francisco José de Caldas. https://revistas.udistrital.edu.co/index.php/infancias/article/view/11627

Pontificia Universidad Javeriana. (2025). Informe LEE 2025: TIC en educación. https://www.javeriana.edu.co/recursosdb/d/lee/inf-113-tic-en-educacion-lee-2025

UNESCO. (2023). Tecnología en la educación: una herramienta para el aprendizaje. https://www.unesco.org/es/articles/informe-de-seguimiento-de-la-educacion-en-el-mundo-2023-tecnol ogia-en-la-educacion-una-herramienta (https://www.unesco.org/es/articles/informe-de-seguimiento-de-la-educacion-en-el-mundo-2023-tecnologia-en-la-educacion-una-herramienta)

Arias, J., & López, F. (2024). Low-Power Long-Range Networks (LoRaWAN) for Monitoring and Safety in Educational Contexts. arXiv:2408.03157. https://arxiv.org/abs/2408.03157 (https://arxiv.org/abs/2408.03157?utm_source=chatgpt.com)

Departamento Administrativo de la Función Pública. (2006). Decreto 6405 de 2006. https://www.funcionpublica.gov.co/eva/gestornormativo/norma.php?i=6405

Mazo, L. (2025, abril 17). Más de 21.000 colegios sin internet y casi 5.000 sin electricidad: radiografía del atraso educativo en Colombia. Infobae.

https://www.infobae.com/colombia/2025/04/17/mas-de-21000-colegios-sin-internet-y-casi-5000-sin-electricidad-radiografia-del-atraso-educativo-en-colombia/ (https://www.infobae.com/colombia/2025/04/17/mas-de-21000-colegios-sin-internet-y-casi-5000-sin-electricidad-radiografia-del-atraso-educativo-en-colombia/)

Unidad de Búsqueda de Personas Dadas por Desaparecidas (UBPD). (2025). Día Internacional de las Manos Rojas 2025 – Balance sobre desapariciones de niños, niñas y adolescentes.
https://unidadbusqueda.gov.co/actualidad/dia-internacional-manos-rojas-2025/

Comité Internacional de la Cruz Roja (CICR). (2024). En Colombia, cada 36 horas desaparece al menos una persona en contexto de conflicto armado y violencia. https://www.icrc.org/es/comunicado-de-prensa/en-colombia-cada-36-horas-desaparece-al-menos-una-persona-en-contexto-conflicto-armado-violencia (https://www.icrc.org/es/comunicado-de-prensa/en-colombia-cada-36-horas-desaparece-al-menos-una-persona-en-contexto-conflicto-armado-violencia)

Teldat. (2024). Internet de las Cosas de Largo Alcance (LoRa): características clave. https://www.teldat.com/es/blog/internet-de-las-cosas-de-largo-alcance-lora/

DANE. (s. f.). ¿Sabías que...?. https://www.dane.gov.co/files/dane-para-ninos/sabias-

Departamento Administrativo de la Función Pública. (s. f.). Norma 49981. https://www.funcionpublica.gov.co/eva/gestornormativo/norma.php?i=49981

Secretaría Distrital de Planeación. (s. f.). ¿Cómo se hace?. https://www.sdp.gov.co/micrositios/ninos-ninas-y-adolescentes/como-se-hace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 (https://www.sdp.gov.co/micrositios/ninos-ninas-y-adolescentes/como-se-hace)

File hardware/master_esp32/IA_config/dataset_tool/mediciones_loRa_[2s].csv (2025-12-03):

timestamp_iso | temp_C | hum_aire_pct | rssi_dBm | snr_dB | label
2025-12-02T18:56:15.045636 | 18.8 | 59.8 | -106.0 | 4.0 | 0
2025-12-02T18:56:20.755798 | 18.8 | 59.5 | -111.0 | -2.0 | 0
2025-12-02T18:56:26.466072 | 18.8 | 59.3 | -120.0 | -7.0 | 0
2025-12-02T18:56:32.175927 | 18.8 | 59.2 | -113.0 | -1.0 | 0
2025-12-02T18:56:39.436645 | 18.8 | 59.0 | -117.0 | -4.0 | 0
2025-12-02T18:56:45.145964 | 18.8 | 58.8 | -115.0 | 0.0 | 0
2025-12-02T18:56:50.854810 | 18.8 | 58.7 | -115.0 | -1.0 | 0
2025-12-02T18:56:56.564372 | 18.8 | 58.6 | -117.0 | -1.0 | 0
2025-12-02T18:57:02.273006 | 18.8 | 58.4 | -113.0 | 0.0 | 0
2025-12-02T18:57:07.982450 | 18.8 | 58.4 | -115.0 | 0.0 | 0
2025-12-02T18:57:13.691577 | 18.8 | 58.3 | -113.0 | 2.0 | 0
2025-12-02T18:57:19.400438 | 18.8 | 58.2 | -114.0 | 0.0 | 0
2025-12-02T18:57:25.109836 | 18.8 | 58.1 | -111.0 | 4.0 | 0
2025-12-02T18:57:30.819067 | 18.8 | 58.1 | -118.0 | -2.0 | 0
2025-12-02T18:57:36.527656 | 18.8 | 58.0 | -117.0 | -2.0 | 0
2025-12-02T18:57:42.237275 | 18.8 | 58.0 | -125.0 | -8.0 | 0
2025-12-02T18:57:47.946317 | 18.8 | 58.0 | -125.0 | -7.0 | 0
2025-12-02T18:57:55.206541 | 18.8 | 57.9 | -120.0 | -5.0 | 0
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

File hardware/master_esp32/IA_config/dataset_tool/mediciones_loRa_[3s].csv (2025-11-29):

timestamp_iso | temp_C | hum_aire_pct | hum_tierra_pct | rssi_dBm | snr_dB | label
2025-11-29T14:23:47.141273 | 20.7 | 57.4 | 5.0 | -48.0 | 9.0 | 0
2025-11-29T14:23:47.141960 | 20.7 | 57.4 | 6.0 | -53.0 | 9.0 | 0
2025-11-29T14:23:47.142611 | 20.7 | 57.4 | 6.0 | -54.0 | 10.0 | 0
2025-11-29T14:23:47.143293 | 20.7 | 57.5 | 5.0 | -46.0 | 9.0 | 0
2025-11-29T14:23:47.143893 | 20.7 | 57.5 | 6.0 | -60.0 | 10.0 | 0
2025-11-29T14:23:47.144427 | 20.7 | 57.5 | 5.0 | -66.0 | 9.0 | 0
2025-11-29T14:23:47.144943 | 20.7 | 57.5 | 6.0 | -50.0 | 9.0 | 0
2025-11-29T14:23:47.145452 | 20.7 | 57.6 | 5.0 | -53.0 | 9.0 | 0
2025-11-29T14:23:47.146003 | 20.7 | 57.6 | 6.0 | -50.0 | 10.0 | 0
2025-11-29T14:23:47.146525 | 20.6 | 57.6 | 6.0 | -52.0 | 10.0 | 0
2025-11-29T14:23:47.147051 | 20.6 | 57.7 | 5.0 | -53.0 | 9.0 | 0
2025-11-29T14:23:47.147619 | 20.6 | 57.7 | 5.0 | -52.0 | 10.0 | 0
2025-11-29T14:23:47.148150 | 20.6 | 57.7 | 6.0 | -53.0 | 9.0 | 0
2025-11-29T14:23:47.148695 | 20.6 | 57.7 | 6.0 | -52.0 | 10.0 | 0
2025-11-29T14:23:47.149212 | 20.6 | 57.7 | 5.0 | -52.0 | 9.0 | 0
2025-11-29T14:23:47.149735 | 20.6 | 57.7 | 7.0 | -53.0 | 10.0 | 0
2025-11-29T14:23:47.765773 | 20.6 | 57.7 | 6.0 | -54.0 | 9.0 | 0
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

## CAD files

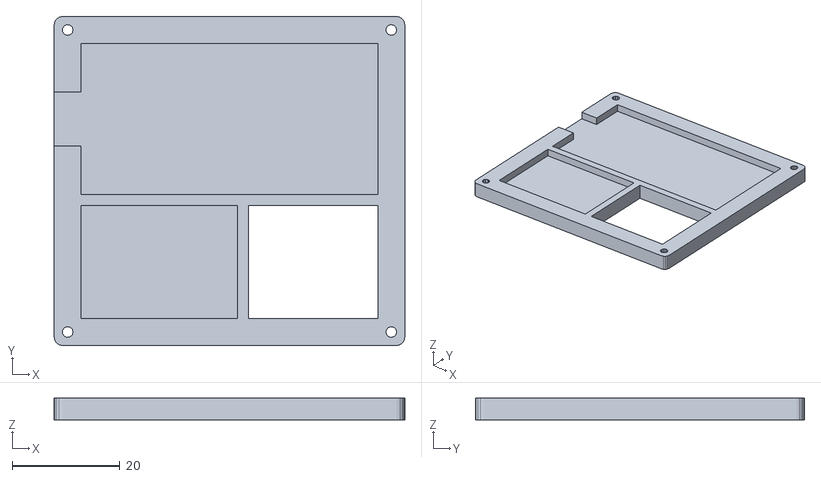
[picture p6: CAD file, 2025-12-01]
3D_models/master/Piso.stl
65.0 x 61.0 x 4.00

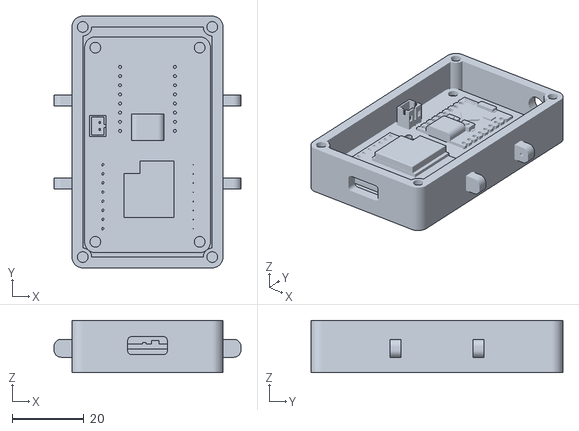
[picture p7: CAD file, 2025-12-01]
3D_models/slave/Waistband_Alltogether_STL.stl
52.0 x 70.0 x 14.5

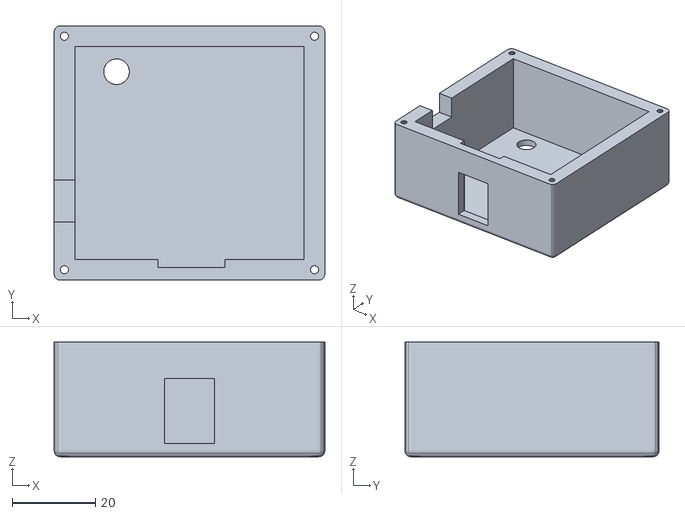
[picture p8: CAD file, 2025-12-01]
3D_models/master/PT.stl
65.0 x 61.0 x 27.5

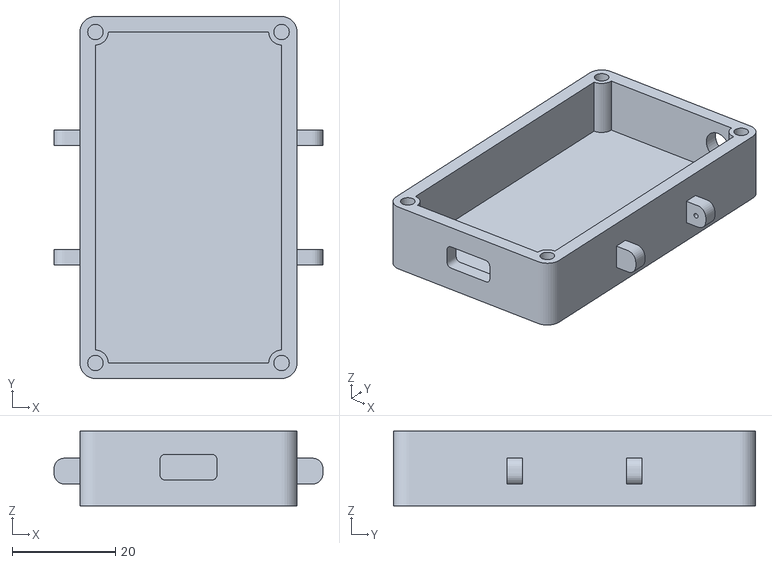
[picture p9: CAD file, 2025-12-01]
3D_models/slave/Base_waistband_stl.stl
52.0 x 70.0 x 14.5

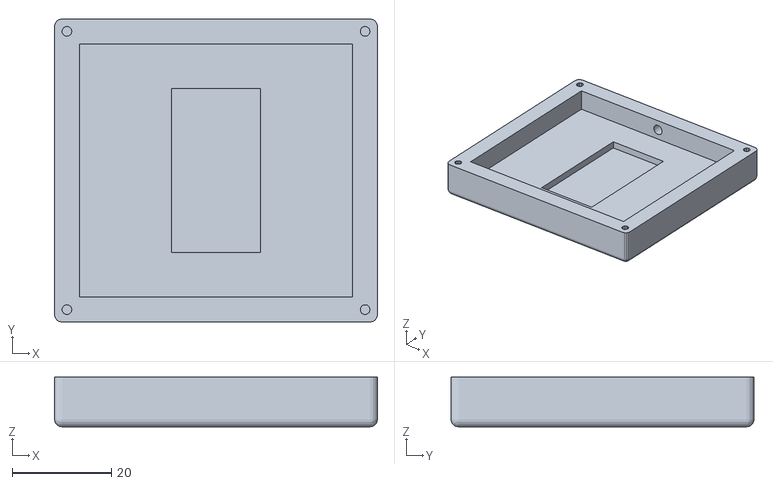
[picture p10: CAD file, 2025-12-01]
3D_models/master/PB.stl
65.0 x 61.0 x 10.0

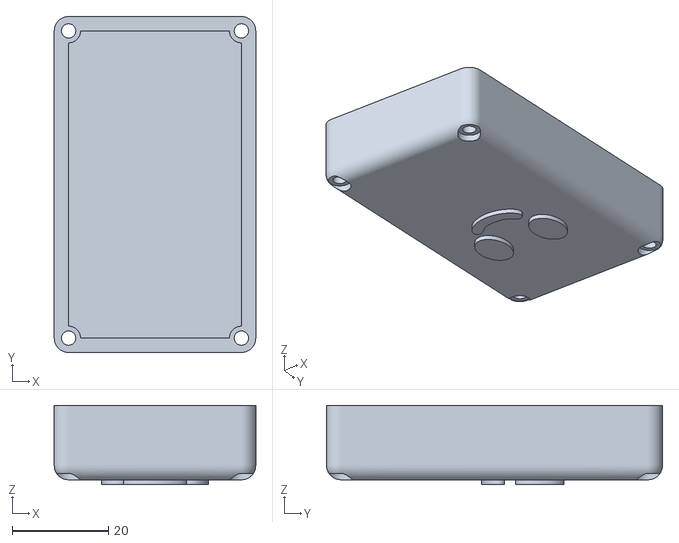
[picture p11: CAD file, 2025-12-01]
3D_models/slave/Top_WaistbandSTL.stl
42.0 x 70.0 x 16.5

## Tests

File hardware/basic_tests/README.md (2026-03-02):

# Basic Tests — LoRa Point-to-Point Link Validation






Minimum firmware to verify SPI wiring and LoRa radio connectivity between the
ESP32 (transmitter) and the ESP32-C3 Mini (receiver) before deploying any
application logic. Run this test first whenever hardware changes are made.

> **This test does not use AutoACK or NetworkID filtering.**
> It is raw unidirectional transmission. For end-to-end AutoACK validation,
> proceed to `master_esp32/ACK_config/`.

---

## Structure

```
basic_tests/
├── esp32/ ← Transmitter (ESP32 DevKit)
│ ├── src/main.cpp
│ └── platformio.ini
└── esp32_mini/ ← Receiver (ESP32-C3 Mini)
├── src/main.cpp
└── platformio.ini
```

---

## Pin Mapping

### ESP32 — Transmitter

| Signal | GPIO |
|---|---|
| SCK | 18 |
| MISO | 19 |
| MOSI | 23 |
| NSS | 5 |
| NRESET | 14 |
| DIO0 | 2 |

### ESP32-C3 Mini — Receiver

| Signal | GPIO |
|---|---|
| SCK | 10 |
| MISO | 5 |
| MOSI | 6 |
| NSS | 7 |
| NRESET | 3 |
| DIO0 | 2 |

> GPIO2, GPIO8 and GPIO9 are strapping pins on the ESP32-C3 — avoid using
> them for LoRa signals. GPIO2 is assigned to DIO0 (interrupt input only,
> driven by the SX1278, not by the MCU at boot).

---

## LoRa Parameters

Both nodes must use identical RF settings:

| Parameter | Value |
|---|---|
| Frequency | 434 MHz |
| Spreading Factor | SF7 |
| Bandwidth | 125 kHz |
| Coding Rate | 4/5 |
| TX Power | 10 dBm |

---

## How to Run

1. Open `esp32/` as a PlatformIO project and flash the transmitter.
2. Open `esp32_mini/` as a separate PlatformIO project and flash the receiver.
3. Open two Serial Monitor sessions simultaneously (115200 baud each).

**Transmitter output (expected):**

```
10dBm Packet> Hello World 1234567890* BytesSent,23 PacketsSent,6
```

**Receiver output (expected):**

```
8s Hello World 1234567890*,RSSI,-44dBm,SNR,9dB,Length,23,Packets,7,Errors,0,IRQreg,50
```

**Receiver timeout (no packets for 60 s):**

```
112s RXTimeout
```

---

## Pass Criteria

| Metric | Expected range |
|---|---|
| RSSI | > −100 dBm at short range |
| SNR | > 0 dB |
| Errors | 0 at < 10 m distance |

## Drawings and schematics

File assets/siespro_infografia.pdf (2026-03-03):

# SIESPRO

## Sistema estudiantil de protección

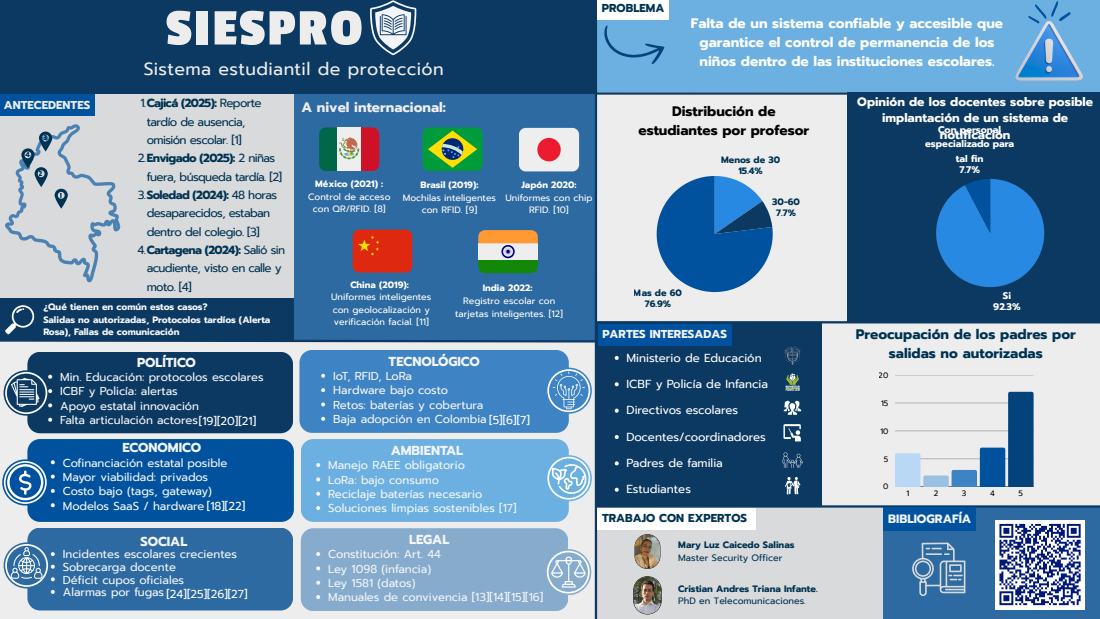
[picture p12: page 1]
Menos de 30 15.4%; Con personal especializado para tal fin 7.7%; BIBLIOGRAFÍA; ANTECEDENTES; Opinión de los docentes sobre posible; notificación; A nivel internacional:; Brasil (2019): Mochilas inteligentes con RFID. [9]; China (2019): Uniformes inteligentes con geolocalización y verificación facial. [11]; POLÍTICO; ECONOMICO; SOCIAL; TECNOLÓGICO; LEGAL; PROBLEMA

Falta de un sistema confiable y accesible que
garantice el control de permanencia de los
niños dentro de las instituciones escolares.

1.Cajicá (2025): Reporte
tardío de ausencia,
omisión escolar. [1]
2.Envigado (2025): 2 niñas
fuera, búsqueda tardía. [2]
3.Soledad (2024): 48 horas
desaparecidos, estaban
dentro del colegio. [3]
4.Cartagena (2024): Salió sin
acudiente, visto en calle y
moto. [4]

Distribución de
estudiantes por profesor

implantación de un sistema de

México (2021) :
Control de acceso
con QR/RFID. [8]

Japón 2020:
Uniformes con chip
RFID. [10]

India 2022:
Registro escolar con
tarjetas inteligentes. [12]

Mas de 60
PARTES INTERESADAS
Ministerio de Educación
ICBF y Policía de Infancia
Directivos escolares
Docentes/coordinadores
Padres de familia
Estudiantes
TRABAJO CON EXPERTOS

¿Qué tienen en común estos casos?
Salidas no autorizadas, Protocolos tardíos (Alerta
Rosa), Fallas de comunicación

Preocupación de los padres por
salidas no autorizadas

Min. Educación: protocolos escolares
ICBF y Policía: alertas
Apoyo estatal innovación
Falta articulación actores

IoT, RFID, LoRa
Hardware bajo costo
Retos: baterías y cobertura
Baja adopción en Colombia
AMBIENTAL

Cofinanciación estatal posible
Mayor viabilidad: privados
Costo bajo (tags, gateway)
Modelos SaaS / hardware

Manejo RAEE obligatorio
LoRa: bajo consumo
Reciclaje baterías necesario
Soluciones limpias sostenibles [17]

Mary Luz Caicedo Salinas
Master Security Officer

Incidentes escolares crecientes
Sobrecarga docente
Déficit cupos oficiales
Alarmas por fugas

Constitución: Art. 44
Ley 1098 (infancia)
Ley 1581 (datos)
Manuales de convivencia [13][14][15][16]

Cristian Andres Triana Infante.
PhD en Telecomunicaciones.

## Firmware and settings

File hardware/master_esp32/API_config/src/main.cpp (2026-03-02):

/*******************************************************************************************************
  SIESPRO - LoRa Master Node / Online Inference Mode (ESP32)
  Reliable transmission with AutoACK using the SX12XX library by Stuart Robinson.
  Reference: example 209_Reliable_Transmitter_AutoACK

  Role: Master node. Reads local sensors, transmits a LoRa packet to the slave,
        extracts link-quality metrics (RSSI, SNR) from the received ACK, and
        sends the data as JSON via HTTPS POST to the backend REST API for
        real-time Random Forest inference.

  Active sensor config: 2 sensors — DHT11 (temperature + humidity)
  CSV format:           temp_C, hum_air_pct, rssi_dBm, snr_dB
  JSON keys:            temperatura, humedad_relativa, rssi, snr

  To enable 3-sensor config (+ HW-080 soil moisture):
    uncomment all lines marked with [3S]
    CSV becomes: temp_C, hum_air_pct, soil_moisture_pct, rssi_dBm, snr_dB
    JSON adds:   "humedad_suelo": <value>
    Note: backend must accept the additional field.
*******************************************************************************************************/

#include <SPI.h>
#include <SX127XLT.h>
#include <Arduino.h>
#include "DHT.h"
#include <WiFi.h>
#include <HTTPClient.h>
#include <WiFiClientSecure.h>

// ===================== WiFi Credentials =====================
// WARNING: do not commit real credentials to a public repository.
// Move these to a credentials.h file and add it to .gitignore.

#include "credentials.h"
const char* ssid     = WIFI_SSID;
const char* password = WIFI_PASSWORD;

// ===================== Backend Endpoint =====================
const char* serverUrl = "https://siespro.onrender.com/sensors/data";

// ===================== SPI Pin Mapping (ESP32) =====================
SX127XLT LT;

#define LORA_SCK   18
#define LORA_MISO  19
#define LORA_MOSI  23
#define NSS        5      // LoRa chip-select
#define NRESET     14     // LoRa reset
#define DIO0       2      // LoRa DIO0 interrupt

#define LORA_DEVICE DEVICE_SX1278
#define TXpower     10

// ===================== Reliable Packet / AutoACK Parameters =====================
#define ACKtimeout 1000    // ms to wait for ACK after transmission
#define TXtimeout  1000    // ms timeout for TX operation
#define TXattempts 10      // max retransmission attempts before giving up

const uint16_t NetworkID = 0x3210;  // Must match slave node

// ===================== LoRa Payload =====================
// LoRa is used only for link quality evaluation (RSSI, SNR from ACK).
// Sensor data is NOT transported via LoRa.
uint8_t  buff[] = "SIESPRO";
uint16_t PayloadCRC;
uint8_t  TXPacketL;

// ===================== DHT11 — Air Temperature & Humidity =====================
#define DHTPIN  17
#define DHTTYPE DHT11
DHT dht(DHTPIN, DHTTYPE);

// ===================== [3S] HW-080 — Soil Moisture =====================
// [3S] const int soilSensorPin = 33;
// [3S] int       soilPercent   = 0;

// ===================== Last Valid Sensor Sample =====================
float lastT            = NAN;
float lastH            = NAN;
// [3S] int lastSoil    = 0;
bool  lastSensorsValid = false;

int16_t AckRSSI = 0;
int8_t  AckSNR  = 0;

// ===================== Forward Declarations =====================
void packet_is_OK();
void packet_is_Error();
void sendData(float tempC, float humAir, int rssi, float snr);
// [3S] void sendData(float tempC, float humAir, int soilPct, int rssi, float snr);


void setup()
{
  Serial.begin(115200);
  Serial.println();
  Serial.println(F("SIESPRO Master - LoRa Online Inference (ESP32)"));

  dht.begin();                              // NOTE: was missing in original 2S version
  // [3S] pinMode(soilSensorPin, INPUT);

  SPI.begin(LORA_SCK, LORA_MISO, LORA_MOSI, NSS);

  if (LT.begin(NSS, NRESET, DIO0, LORA_DEVICE))
  {
    Serial.println(F("LoRa device found"));
    delay(1000);
  }
  else
  {
    Serial.println(F("No LoRa device responding"));
    while (1) { delay(2000); }
  }

  LT.setupLoRa(
      434000000,    // carrier frequency (Hz) — SX1278 433 MHz band
      0,            // frequency offset
      LORA_SF7,     // spreading factor
      LORA_BW_125,  // bandwidth
      LORA_CR_4_5,  // coding rate
      LDRO_AUTO     // low data rate optimization
  );

  Serial.println(F("Transmitter ready"));
  Serial.println();
  Serial.println(F("CSV: temp_C,hum_air_pct,rssi_dBm,snr_dB"));
  // [3S] Serial.println(F("CSV: temp_C,hum_air_pct,soil_moisture_pct,rssi_dBm,snr_dB"));
  Serial.println();

  // ===================== WiFi Setup =====================
  WiFi.begin(ssid, password);
  Serial.print(F("Connecting to WiFi"));

  unsigned long start = millis();
  while (WiFi.status() != WL_CONNECTED)
  {
    delay(300);
    Serial.print(F("."));
    if (millis() - start > 30000)
    {
      Serial.println();
      Serial.println(F("WiFi connection timeout"));
      break;
    }
  }

  if (WiFi.status() == WL_CONNECTED)
  {
    Serial.println();
    Serial.println(F("WiFi connected"));
    Serial.print(F("IP: "));
    Serial.println(WiFi.localIP());
  }
  else
  {
    Serial.println(F("WiFi NOT connected"));
  }

  Serial.println();
}


void loop()
{
  // ===================== Sensor Readings =====================
  float h = dht.readHumidity();
  float t = dht.readTemperature();
  float f = dht.readTemperature(true);   // Fahrenheit — unused but validates sensor response

  Serial.println(F("=== Sensor readings ==="));

  if (isnan(h) || isnan(t) || isnan(f))
  {
    Serial.println(F("DHT11 read failed"));
    lastSensorsValid = false;
  }
  else
  {
    // [3S] soilPercent = map(analogRead(soilSensorPin), 4092, 0, 0, 100);

    Serial.print(F("DHT11  | Humidity: ")); Serial.print(h);
    Serial.print(F("%  Temp: "));           Serial.print(t);
    Serial.print(F(" °C / "));              Serial.print(f);
    Serial.println(F(" °F"));

    // [3S] Serial.print(F("HW-080 | Soil moisture: "));
    // [3S] Serial.print(soilPercent);
    // [3S] Serial.println(F(" %"));

    lastT = t;
    lastH = h;
    // [3S] lastSoil = soilPercent;
    lastSensorsValid = true;
  }

  Serial.println();

  // ===================== Reliable Transmission with AutoACK =====================
  uint8_t attempts = TXattempts;
  TXPacketL = 0;

  do
  {
    Serial.print(F("Transmit payload > "));
    LT.printASCIIArray(buff, sizeof(buff));
    Serial.println();
    Serial.flush();

    Serial.print(F("Send attempt "));
    Serial.println(TXattempts - attempts + 1);

    TXPacketL = LT.transmitReliableAutoACK(
        buff,
        sizeof(buff),
        NetworkID,
        ACKtimeout,
        TXtimeout,
        TXpower,
        WAIT_TX
    );
    attempts--;

    if (TXPacketL > 0)
    {
      PayloadCRC = LT.getTXPayloadCRC(TXPacketL);
      AckRSSI    = LT.readPacketRSSI();
      AckSNR     = LT.readPacketSNR();

      packet_is_OK();

      if (lastSensorsValid)
      {
        // ===================== CSV Output =====================
        Serial.println();
        Serial.print(lastT);   Serial.print(F(","));
        Serial.print(lastH);   Serial.print(F(","));
        // [3S] Serial.print(lastSoil); Serial.print(F(","));
        Serial.print(AckRSSI); Serial.print(F(","));
        Serial.println(AckSNR);

        // ===================== HTTPS POST to API =====================
        sendData(lastT, lastH, AckRSSI, (float)AckSNR);
        // [3S] sendData(lastT, lastH, lastSoil, AckRSSI, (float)AckSNR);
      }

      Serial.println();
    }
    else
    {
      packet_is_Error();
      Serial.println();
    }

    delay(500);
  }
  while ((TXPacketL == 0) && (attempts != 0));

  if (TXPacketL > 0)
    Serial.println(F("Packet acknowledged"));

  if (attempts == 0)
  {
    Serial.print(F("No acknowledge after "));
    Serial.print(TXattempts);
    Serial.println(F(" attempts"));
  }

  Serial.println();
  delay(10000);
}


void packet_is_OK()
{
  Serial.print(F("LocalNetworkID,0x"));
  Serial.print(NetworkID, HEX);
  Serial.print(F(",TransmittedPayloadCRC,0x"));
  Serial.println(PayloadCRC, HEX);
}


void packet_is_Error()
{
  Serial.println(F("No packet acknowledge"));
  LT.printIrqStatus();
  LT.printReliableStatus();
}


// ===================== HTTPS POST =====================
// Sends JSON sensor + link-quality data to the backend for RF inference.
// setInsecure() disables certificate validation — acceptable for demo/academic use.
void sendData(float tempC, float humAir, int rssi, float snr)
// [3S] void sendData(float tempC, float humAir, int soilPct, int rssi, float snr)
{
  if (WiFi.status() != WL_CONNECTED)
  {
    Serial.println(F("WiFi not connected, skipping API call"));
    return;
  }

  String jsonData = "{";
  jsonData += "\"temperatura\": "      + String(tempC, 2) + ",";
  jsonData += "\"humedad_relativa\": " + String(humAir, 2) + ",";
  // [3S] jsonData += "\"humedad_suelo\": " + String(soilPct) + ",";
  jsonData += "\"rssi\": "             + String(rssi) + ",";
  jsonData += "\"snr\": "              + String(snr, 2);
  jsonData += "}";

  Serial.print(F("JSON: "));
  Serial.println(jsonData);

  WiFiClientSecure client;
  client.setInsecure();

  HTTPClient http;
  http.begin(client, serverUrl);
  http.addHeader("Content-Type", "application/json");

  int httpCode = http.POST(jsonData);

  if (httpCode > 0)
  {
    Serial.print(F("HTTP POST OK, code: "));
    Serial.println(httpCode);
    Serial.print(F("Response: "));
    Serial.println(http.getString());
  }
  else
  {
    Serial.print(F("HTTP POST failed, code: "));
    Serial.println(httpCode);
  }

  http.end();
}

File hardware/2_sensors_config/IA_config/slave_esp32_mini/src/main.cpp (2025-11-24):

/*******************************************************************************************************
  Programs for Arduino - Copyright of the author Stuart Robinson - 02/03/20

  This program is supplied as is. It is up to the user to determine whether the program is suitable
  for the intended purpose and free from errors.
*******************************************************************************************************/

/*******************************************************************************************************
  Program Operation
  -----------------
  This sketch implements a minimal LoRa receiver using the SX127XLT library. It listens for incoming
  packets using the LoRa settings configured in LT.setupLoRa().

  The received packet is assumed to contain ASCII-printable text. If the packet contains non-ASCII
  bytes (outside 0x20–0x7F), the serial output may show unexpected characters.

  Example output (valid packet):
      8s  Hello World 1234567890*,RSSI,-44dBm,SNR,9dB,Length,23,Packets,7,Errors,0,IRQreg,50

  Example output (CRC error):
      137s PacketError,RSSI,-89dBm,SNR,-8dB,Length,23,Packets,37,Errors,2,IRQreg,70,
           IRQ_HEADER_VALID,IRQ_CRC_ERROR,IRQ_RX_DONE

  Example timeout (no packets in 10 seconds):
      112s RXTimeout

  For more advanced receiver options see example "104_LoRa_Receiver".

  Serial monitor baud rate: 115200
*******************************************************************************************************/

#include <Arduino.h>        // Required for ESP32 and Arduino framework
#include <SPI.h>            // SX127x LoRa module communicates via SPI
#include <SX127XLT.h>       // SX127x LoRa driver library

SX127XLT LT;                // Create LoRa driver instance

// ===================== LoRa Pin Definitions (ESP32-C3 Mini) =====================
// These pins avoid strapping pins such as GPIO2, GPIO8, GPIO9.
#define LORA_SCK   10       // SPI SCK
#define LORA_MISO  6        // SPI MISO
#define LORA_MOSI  5        // SPI MOSI

#define NSS        7        // LoRa chip select (NSS / CS)
#define NRESET     3        // LoRa reset pin
#define DIO0       2        // LoRa DIO0 interrupt pin (RX/TX done)

#define LORA_DEVICE DEVICE_SX1278
#define RXBUFFER_SIZE 255   // Maximum payload size to receive

// ===================== Packet Statistics =====================
uint32_t RXpacketCount = 0;   // Total received packets
uint32_t errors = 0;          // Total packet errors

// ===================== RX Buffers and Metadata =====================
uint8_t RXBUFFER[RXBUFFER_SIZE];  // Buffer to hold received data
uint8_t RXPacketL;                // Length of last received packet
int16_t PacketRSSI;               // RSSI of received packet
int8_t  PacketSNR;                // SNR of received packet

// Function prototypes
void packet_is_OK();
void packet_is_Error();
void printElapsedTime();


/*******************************************************************************************************
  SETUP
*******************************************************************************************************/
void setup()
{
  Serial.begin(9600);
  delay(2000);    // Allow USB CDC to enumerate before printing
  Serial.println();
  Serial.println(F("4_LoRa_Receiver Starting"));
  Serial.println();

  // Initialize SPI with explicit pin mapping for ESP32-C3 Mini
  SPI.begin(LORA_SCK, LORA_MISO, LORA_MOSI, NSS);

  // Initialize LoRa module
  if (LT.begin(NSS, NRESET, DIO0, LORA_DEVICE))
  {
    Serial.println(F("LoRa device found"));
    delay(1000);
  }
  else
  {
    Serial.println(F("No LoRa device responding"));
    while (1)
    {
      delay(2000);    // Prevent watchdog resets
    }
  }

  // Configure LoRa modem
  LT.setupLoRa(
      434000000,   // Frequency (Hz)
      0,           // Frequency offset
      LORA_SF7,    // Spreading factor
      LORA_BW_125, // Bandwidth
      LORA_CR_4_5, // Coding rate
      LDRO_AUTO    // Low-data-rate optimization
  );

  Serial.print(F("Receiver ready - RXBUFFER_SIZE "));
  Serial.println(RXBUFFER_SIZE);
  Serial.println();
}


/*******************************************************************************************************
  LOOP
*******************************************************************************************************/
void loop()
{
  // Wait up to 60 seconds (60000 ms) for a packet.
  RXPacketL = LT.receive(RXBUFFER, RXBUFFER_SIZE, 60000, WAIT_RX);

  PacketRSSI = LT.readPacketRSSI();   // Read RSSI of last received packet
  PacketSNR  = LT.readPacketSNR();    // Read SNR of last received packet

  if (RXPacketL == 0)
  {
    // Packet failed validation at LoRa hardware level (CRC / header)
    packet_is_Error();
  }
  else
  {
    packet_is_OK();
  }

  Serial.println();
}


/*******************************************************************************************************
  VALID PACKET HANDLER
*******************************************************************************************************/
void packet_is_OK()
{
  uint16_t IRQStatus;

  RXpacketCount++;
  IRQStatus = LT.readIrqStatus();      // Read IRQ flags from LoRa device
  //printElapsedTime();                  // Print uptime in seconds

  //Serial.print(F("  "));

  // Print received ASCII payload
  LT.printASCIIPacket(RXBUFFER, RXPacketL);

  // Append metadata: RSSI, SNR, packet length, counters, IRQ flags
  //Serial.print(F(",RSSI,"));
  Serial.print(F(","));
  Serial.print(PacketRSSI);
  //Serial.print(F("dBm,SNR,"));
  Serial.print(F(","));
  Serial.print(PacketSNR);
  //Serial.print(F("dB,Length,"));
  //Serial.print(RXPacketL);
  //Serial.print(F(",Packets,"));
  //Serial.print(RXpacketCount);
  //Serial.print(F(",Errors,"));
  //Serial.print(errors);
  //Serial.print(F(",IRQreg,"));
  //Serial.print(IRQStatus, HEX);
}


/*******************************************************************************************************
  ERROR HANDLER
*******************************************************************************************************/
void packet_is_Error()
{
  uint16_t IRQStatus = LT.readIrqStatus();

  printElapsedTime();

  if (IRQStatus & IRQ_RX_TIMEOUT)
  {
    // No packet received before timeout
    Serial.print(F(" RXTimeout"));
  }
  else
  {
    // Packet received but failed CRC or header validation
    errors++;
    //Serial.print(F(" PacketError"));
    //Serial.print(F(",RSSI,"));
    Serial.print(F(","));
    Serial.print(PacketRSSI);
    //Serial.print(F("dBm,SNR,"));
    Serial.print(F(","));
    Serial.print(PacketSNR);
    //Serial.print(F("dB,Length,"));
    //Serial.print(LT.readRXPacketL());
    //Serial.print(F(",Packets,"));
    //Serial.print(RXpacketCount);
    //Serial.print(F(",Errors,"));
    //Serial.print(errors);
    //Serial.print(F(",IRQreg,"));
    //Serial.print(IRQStatus, HEX);

    // Print human-readable names of IRQ flags
    //LT.printIrqStatus();
  }
}
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

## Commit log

2025-11-03 añadiendo proyectos platformio
    [pyvenv.cfg]
2025-11-04 probando platformio con esp32 y arduino
2025-11-21 ejemplos básicos - se confirmó correcto funcionamiento de los 4 LoRa, esp32 y esp32 mini
    [main.cpp]
2025-11-23 código sensores
2025-11-23 añadiendo códigos para toma de datos del modelo de IA - elimando carpeta de experimentos
2025-11-24 añadiendo script python para toma de datos etiquetados
    [mediciones_loRa.csv]
2025-11-24 poniendo carpeta hw
    [mediciones_loRa.csv]
2025-11-29 mediciones para entrenar random forest
    [mediciones_loRa.csv]
2025-12-01 Slave's 3D Model
    [Base_Waistband.3mf, Top_waistband.3mf, Wasitband_AllTogether.3mf]
2025-12-01 Slave´s 3D models in STL format
    [Top_WaistbandSTL.stl]
2025-12-01 Others slave's 3D models in STL format
    [Base_waistband_stl.stl, Waistband_Alltogether_STL.stl]
2025-12-01 organizando modelos 3D
    [Base_Waistband.3mf, PB.stl, PT.stl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]
2025-12-02 adding 2 sensors config
    [mediciones_loRa.csv]
2025-12-02 rename folders
    [mediciones_loRa.csv]
2025-12-02 adding IA config 2 sensor working
2025-12-02 adding 2 sensor API config full working
2025-12-02 training model 2 sensors
    [mediciones_loRa.csv]
2025-12-03 training model 2 sensors cyt
    [mediciones_loRa.csv, mediciones_loRa_1.csv]
2025-12-03 training model 2 sensors cyt 2nd time
    [mediciones_loRa.csv, mediciones_loRa_2.csv]
2025-12-03 añadiendo datos salon
    [mediciones_loRa.csv, mediciones_loRa_3.csv]
2026-02-02 addign prototype image
2026-03-02 adding organized hardware section
    [mediciones_loRa_1.csv, mediciones_loRa_3.csv, mediciones_loRa_[2s].csv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]
2026-03-03 adding docs section
    [Base_waistband_stl.stl, PB.stl, PT.stl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]
